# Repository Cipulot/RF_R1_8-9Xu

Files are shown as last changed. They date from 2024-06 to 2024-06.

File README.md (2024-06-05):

# RF_R1_8-9Xu

Open source universal PCB for the Realforce R1 family of keyboards.

## Introduction

This project is a continuation of my development of open source EC boards.

The supported layouts are the one of the Realforce R1 family of keyboards, it being ANSI, ISO or JIS.

## Technical information

- Layout size: tenkeykess (TKL)
- Compatible switches: EC switches (Topre and NIZ)
- Microcontroller: STM32F401
- Connector:
    * internal USB-C
    * original JST connector S4B-EH(LF)(SN)
    * jst connector for daughterboard
- Addressable RGB strip support
- Firmware compatibility: QMK (with VIA/VIAL support)
- Protection hardware (on all connection methods):
  * Fused
  * ESD protection

## Renders and Prototypes

### Render

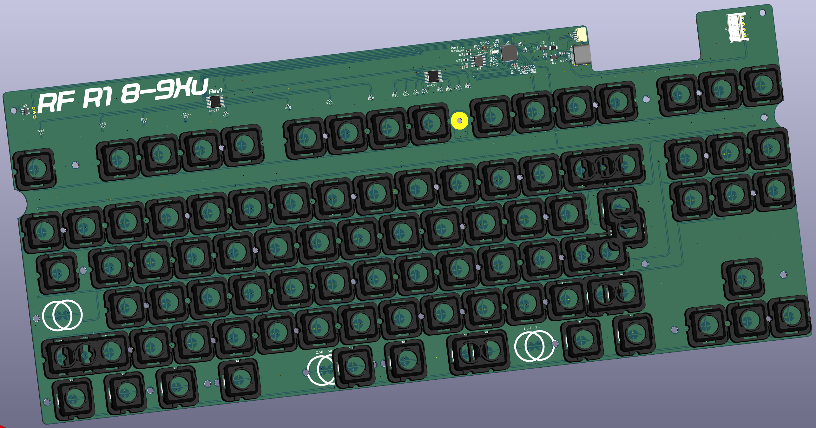
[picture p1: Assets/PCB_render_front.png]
PCB Front Render


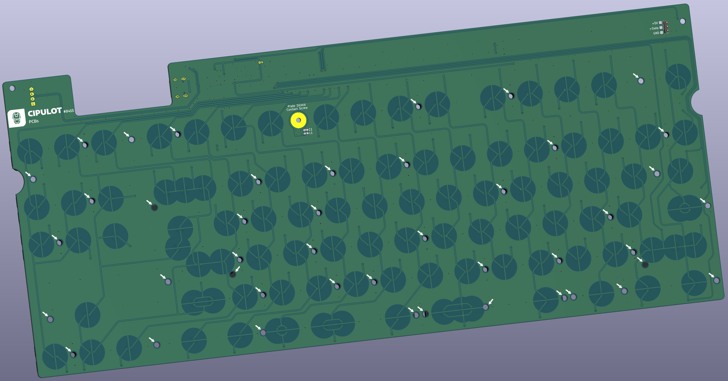
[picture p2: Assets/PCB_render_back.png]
PCB Back Render


### Prototype

PCB Front Proto

PCB Back Proto

## Revisions and relative features

### Rev1

This revision implements all the main features of the PCB.

#### Connectivity

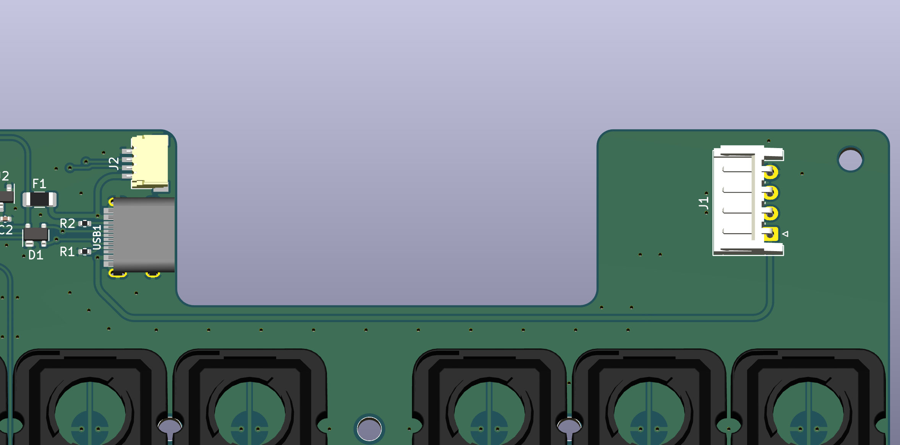
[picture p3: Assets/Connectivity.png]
Connectivity


Since this is first and foremost a replacement PCB for the original Realforce R1 PCB, the original JST connector is still supported. It's been moved to the right to accommodate the new JST connector for the daughterboard and the USB-C connector.

I thought about adding extra connectors so that if anyone wants to use this PCB in a custom project they can have the flexibility to use the connector that they prefer.

#### Addressable RGB strip support

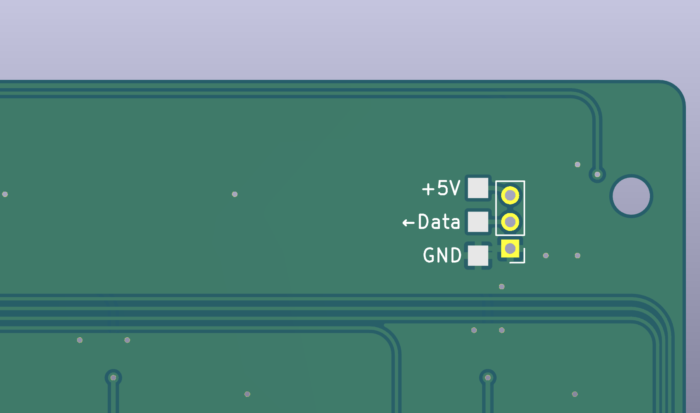
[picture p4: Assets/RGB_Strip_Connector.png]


Since the R1 PCB is used in some already existing custom PC (polycarbonate) cases, it was important to have a way to include a RGB strip support.

The strip can be directly sticked to the PCB and then wired to the PCB by soldering the pins to the THT pins or SMD pads.

Lighting can be controlled by the board itself and customization is achieved by using Vial/VIA.

### Rev 1.1

This revision implements the following changes:
  * added support for THT LED for Caps Lock and Scroll Lock
  * moved filtering components for plate shield to top side
  * added filtering components for USB-C shield
  * improved ground stitching

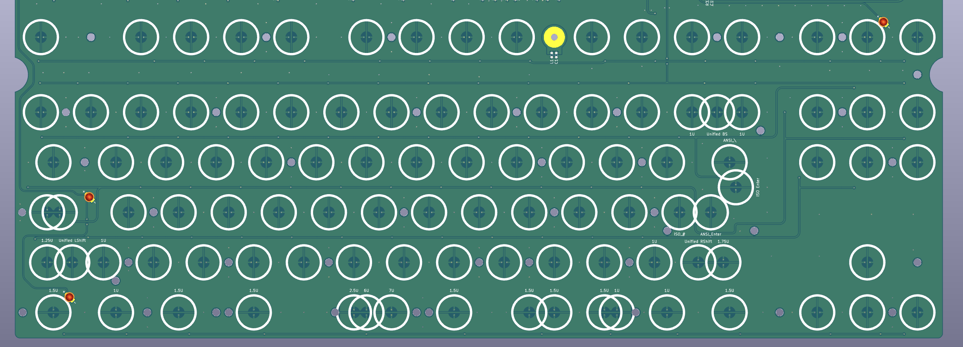
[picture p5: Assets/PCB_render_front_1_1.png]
PCB Front Render Rev 1.1


## "Why no plates?" I hear you say

It is what it is.

walky

For real though, the PCB is a replacement for the original Realforce R1 PCB so using the original plates is the preferred option. Furthermore, the multilayout support makes it tedious to make a plate design for each and every layout.

Nevertheless, if there's a particular plate config you want to use, you can always open an issue on the repository or even better make a PR from your own fork.

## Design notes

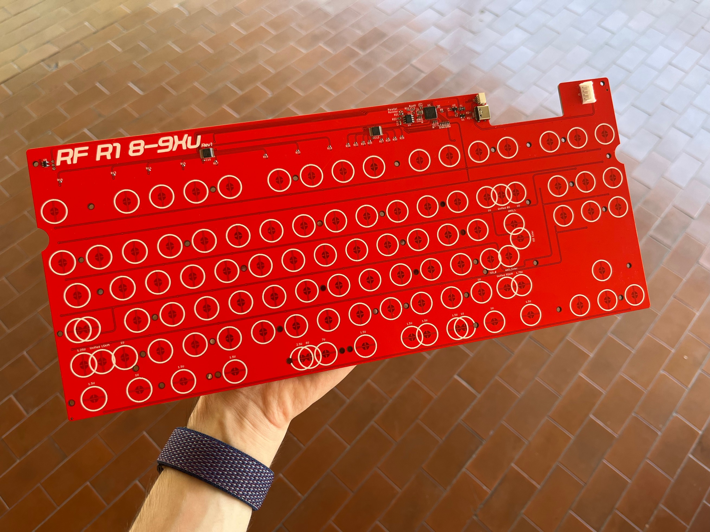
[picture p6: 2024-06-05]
Assets/PCB_proto_social.png

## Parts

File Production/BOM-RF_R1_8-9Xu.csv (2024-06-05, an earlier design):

Comment | Designator | Footprint | LCSC
STM32F401CBUx | U1 | QFN-48-1EP_7x7mm_P0.5mm_EP5.6x5.6mm | C118825
100n | C1,C13,C2 | C_0603_1608Metric | C14663
JST | J2 | JST-SR-4 | C160404
HRO-TYPE-C-31-M-12 | USB1 | HRO-TYPE-C-31-M-12-Assembly | C165948
1k | R23 | R_0603_1608Metric | C21190
330 | R1 | R_0603_1608Metric | C23138
4.7u | C3 | C_0402_1005Metric | C23733
100 | R10,R32,R33,R4,R5,R7,R8,R9 | R_0402_1005Metric | C25076
100k | R14,R15,R16,R17,R18,R19,R20,R21,R24,R25,R26,R27,R28,R29,R30,R31,R6 | R_0402_1005Metric | C25741
10k | R11,R12,R13 | R_0402_1005Metric | C25744
100k | R22 | R_0603_1608Metric | C25803
5.1k | R2,R3 | R_0402_1005Metric | C25905
JST | J1 | JST_EH_S4B-EH_1x04_P2.50mm_Horizontal | C265068
PRTR5V0U2X | D1 | SOT-143 | C2827688
100n | C10,C12,C15,C6,C7,C8,C9 | C_0402_1005Metric | C307331
8 MHz | Y1 | Resonator_SMD_Murata_CSTxExxV-3Pin_3.0x1.1mm | C341525
ME6206A33M3G | U3 | SOT-23 | C35259
CD74HC4051PWR | U4,U6 | TSSOP16 | C352826
220p | C14 | C_0603_1608Metric | C519500
1u | C11,C4,C5 | C_0402_1005Metric | C52923
500mA | F1 | Fuse_1206_3216Metric | C70076
OPA340NA | U5 | SOT-23-5 | C73479
SN74AHCT1G125 | U2 | SOT-23-5 | C7484
220 @ 100MHz, 2A | L1 | L_0603_1608Metric | C85832

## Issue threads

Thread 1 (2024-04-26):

PCBway

civarson, 2024-04-26:
Hi, thank you for providing this. I just submitted an order to print one of these based on the files you've provided (gerber files and BOM) and included assembly in the order. Note that for the BOM item "220 @ 100MHz, 2A", the part number you reference is 330 ohms and not 220 (C85832).

Is there anything else I need to know since this is my first time doing it? I am doing this as I've always wanted to get a custom PCB printed, plus I have been eager to convert my R1 to usb-c for several years now.

My minimum order is 5 assembled boards if anyone wants to DM me to purchase (cost + shipping). I'll have 4 leftover!

Cipulot, 2024-04-26:
@civarson that will be fixed.

If you want to purchase a unit, they are currently available for purchase at Cannonkeys.

As a final note, please, do not utilize the GH issues as a marketplace for the leftovers MOQ.....

Closed 2024-04-26.

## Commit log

2023-11-17 Updated sheets
    [RF_R1_8-9Xu.kicad_sch, analog.kicad_sch, indicators.kicad_sch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]
2023-11-23 Rev 1.2
    [BOM-RF_R1_8-9Xu.csv, RF_R1_8-9Xu.kicad_sch, analog.kicad_sch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]
2024-06-05 RF R1 Cleanup
    [BOM-RF_R1_8-9Xu.csv, RF_R1_8-9Xu.kicad_sch, analog.kicad_sch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]
